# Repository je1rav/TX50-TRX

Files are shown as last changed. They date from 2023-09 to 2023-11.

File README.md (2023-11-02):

# TX50（CRkits共同購入プロジェクト）の改造

 CRkits共同購入プロジェクトで頒布されているTX50送信機（http://jl1kra.sakura.ne.jp/TX50R50.html
 ) を改造し，シンプルなAMトランシーバーにしました．  

## TX50送信機の複数周波数で通信可能なトランシーバーへの改造
TX50は元々JH1FCZ氏が開発された10mW出力のトランスレス50MHz帯コレクタ変調AM送信機をCRkits共同購入プロジェクトが復刻キット化したものです．  
キットでは水晶発振器で50.55MHzあるいは50.62MHzを発生させ，その周波数で運用します．  
QP-7Cの改造との場合と同様に，まず，発振段にSi5351モジュールを使用することで，複数周波数での使用を容易にしました．  
また，Si5351は，複数の端子に比較的自由な周波数の信号を出力できますので，それを利用したスーパーヘテロダイン受信機を作成し，トランシーバー化しました．  
受信機のAFアンプには，TX50送信機のマイクアンプ(LM386)を使い回し，スピーカー出力にしました．  
電源には006P(9V)を使用し，PTTスイッチで送受信を切り替えました． 

改造は以下の2点です．  

### 1．発振段のSi5351化
	Si5351モジュール（秋月電子）を使用し，発振出力をファイナル段に入力しました．  
	ファイナル段の入力は自己バイアス回路とし，Si5351の出力をコンデンサを介してベースに導入しています． 
	2N3904のベースーコレクタ間に自己バイアス用に100kΩの抵抗を接続しています． 
	T2とC13無しの直結状態で，無変調時に7.6mWの出力を確認しました．  
	新スプリアス規格のスプリアス領域の信号強度50μW(-13dBm)以下を満たしています． 
	Si5351モジュールは，Seeed Xiao RP2040でI2Cインターフェースを介して制御しました．  
	タクトスイッチで，プリセットした周波数を順次変更できるようにしました．  
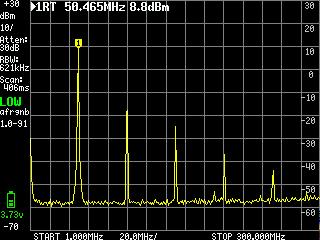
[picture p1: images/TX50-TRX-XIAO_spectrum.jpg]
スプリアス
  
TinySAによる送信スペクトル測定結果（T2とC13無し，無変調時）

### 2．シングルスーパー受信機を使用したトランシーバー化  
	QP-7Cの改造の場合と同様にラジオICであるCD2003を使用し，IF 450kHz(あるいは455kHz)で，セラミックフィルターによる帯域制限を行いました．  
	局所発振信号はSi5351モジュールから加えています．  
	AFアンプにはTX50のマイクアンプを，切り替えて使用しています．  
	プリRFアンプなしでの最終的な感度は50MHz帯で-75dbmのAM信号がかろうじて検知できる程度でした(TinySAと耳による)．  
	送受信の切り替えは，4回路2接点のプッシュスイッチを　PTTスイッチとして使用しました．  
   
回路図は，
回路図pdfファイル  
赤丸はTX50送信機キットの部品をそのまま使用，ピンク丸はキットで余った部品を流用，それ以外は別途準備した部品です．  
受信部はCD2003を使用したシングルスーパー受信機です．  
50MHz帯では感度が不足しそうですが，今回は送信機出力が10mWとQRPpなのでプリアンプなしで製作しました．  
IFフィルターにはLTMxxxYYが使用できます．とりあえず，LTM450IWで作りました．  
アンテナコネクタの近くのT2とC13はロッドアンテナを使用した場合のマッチング用ですので，使用しない時は取り付けないで，基板のT2の1番ピンと5番ピンをショートします．  
ロッドアンテナを使用する場合，この回路はGAWANTもどきで調整が必要です(具体的な調整は変更申請が終わってから行う予定です)．  
(option)で示された部品はOLED接続用，OLEDに対応した詳細な周波数変更用のタクトスイッチ，およびSSB受信用のBFO部品です．  
AGC電圧をSeeed Xiao RP2040のアナログ入力に接続してあるので，OLEDを繋げば信号強度の表示も可能なはずです．  
(option)部分の利用に関するプログラムは，現時点では作っておらず，具体的な作成計画もありません．  

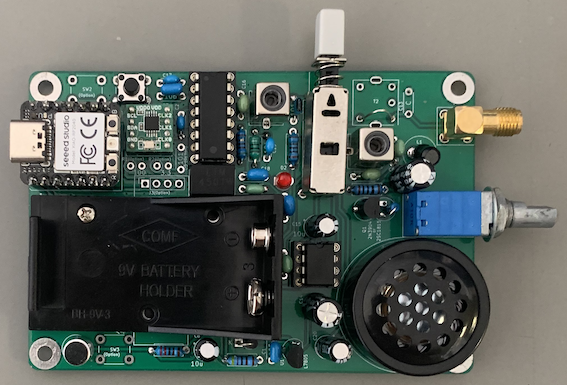
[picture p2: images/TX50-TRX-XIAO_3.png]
   
ロッドアンテナ不使用で部品をつけた状態（プロトタイプ基板）  
  
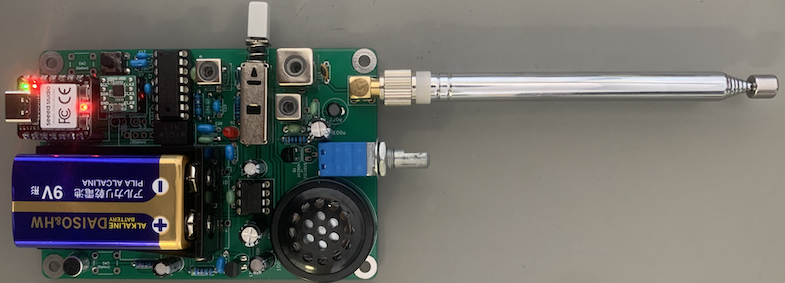
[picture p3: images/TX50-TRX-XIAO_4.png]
  
ロッドアンテナ仕様にした状態（プロトタイプ基板）  

受信機の入力段に送信機キットで余ったDIY7をBPFとして挿入していますので，受信感度が最大になるようにコアを調整する必要があります．  
もちろん送信部のコアの調整も必要です

#### Seeed Xiao RP2040用スケッチは"TX50-TRX-XIAO.ino"です．  
	ボードマネージャは，Earlephilhower版 Raspberry Pi Pico/RP2040が使用できます．
	この際，ボードとしてSeeed Xiao RP2040を選んでください． 
 	また，消費電流を減らすため．CPU Speedは最低の50MHzにセットして下さい． 
  	プログラムの62行目の”set_sys_clock_khz(18000, true);”を有効にすると，システムクロックは18MHzまで下がって，消費電流がさらに減少します． 
   	但し，このクロック周波数ではUSBシリアル通信機能が失われますので，新たに別のプログラムを書き込みたい場合は．一旦，プログラミングモードにする必要があります． 
   	（プログラミングモードは，BOOTボタンを押しながらRESETボタンを押すと入れます． USBメモリの様にマウントされます．） 
	今回はUSB Audioを使用していないので，Raspberry Pi Pico mbed版は必要ありません． 
	どうしてもmbed版を使いたい場合はQP-7C_RP2040のページを参照して下さい． 
	SI5351aの制御には，"Etherkit SI5351"ライブラリーを使用しました． 
	選択周波数はオンボードのカラーLEDの色で表示することにし，その制御には"Adafruit_NeoPixel"ライブラリーを使用しました． 
	#define FREQ_0 から　#define FREQ_6 で運用したい周波数を設定します． 
	タクトスイッチを押すたびに，次々に周波数が変化し，カラーLEDの色が変わります． 
	
#### JLCPCB用のガーバーファイルは"TX50-TRX-XIAO_gerber.zip"で，Kicadのファイルは"TX50-TRX-XIAO_kicad.zip"です．  
	実際にはプロトタイプ版で動作テストをしており， これはそのマイナーチェンジ版(現時点では未テスト)です．  
 
#### ケースの3Dプリンタデータファイルは"TX50-TRX-XIAO-BOX_stl.zip"です．  
	M3 35mmネジ 4本で固定できます．  
 	USB充電式9V充電池(006P型)用の充電穴をつけたパネルも含めました．  
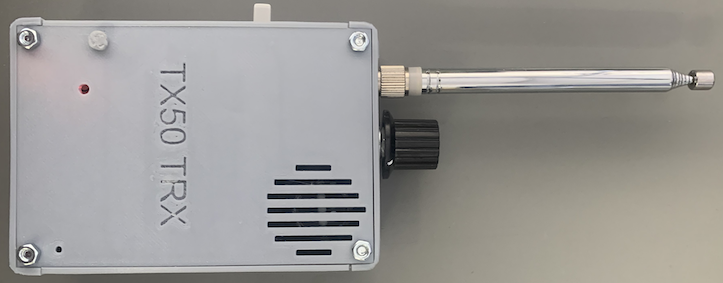
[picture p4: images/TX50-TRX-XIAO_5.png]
  

#### 必要部品(2023年9月27日時点の価格)  
	TX50キット：CRkits共同購入プロジェクト，1850円 + 180円（送料）　http://jl1kra.sakura.ne.jp/TX50R50.html  
	Seeed Xiao RP2040：たとえば秋月電子 830円　https://akizukidenshi.com/catalog/g/gM-17044/
	秋月電子Si5351モジュール：秋月電子，500円　https://akizukidenshi.com/catalog/g/gK-10679/  
	8ピンICソケット（秋月電子Si5351モジュール用）：1個
	CD2003GP：たとえばaitendo，165円　https://www.aitendo.com/product/1528
	16ピンICソケット（CD2003GP用）：1個
	LTM455IW or LTM450IW：秋月電子，1個110円(LTM455IW) or 10個300円(LTM450IW) https://akizukidenshi.com/catalog/g/gP-16374/ or https://akizukidenshi.com/catalog/g/gP-16052/
	三端子レギュレーター　５Ｖ１００ｍＡ：例えば，TA78L05S　秋月電子，20円　https://akizukidenshi.com/catalog/g/gI-08973/
	分割ロングピンソケット　１×４２（Seeed Xiao RP2040ソケット受けが必要ならば）：秋月電子，1個80円　https://akizukidenshi.com/catalog/g/gC-05779/  
	ピンヘッダ　１×４０：（Seeed Xiao RP2040用）秋月電子，1個35円　https://akizukidenshi.com/catalog/g/gC-00167/  
	プッシュボタンPS-42F42：aliexpress（ロックなし，あるいはロック付き）やaitendo（ロック付き 44円，ただし準備中）
	基板取付用２連ボリューム　スイッチ付　A10ｋΩ：秋月電子，180円　https://akizukidenshi.com/catalog/g/gP-12579/
	基板取付用スピーカーユニットUGSM30A-8-01：秋月電子，120円　https://akizukidenshi.com/catalog/g/gP-09270/
	006P電池ホルダー BH-9V-3P24：秋月電子，50円　https://akizukidenshi.com/catalog/g/gP-08160/
	タクトスイッチ：例えば秋月電子，15円　https://akizukidenshi.com/catalog/g/gP-17166/
	整流用ショットキーダイオード：例えば１Ｓ４，秋月電子10本　140円　https://akizukidenshi.com/catalog/g/gI-16384/
	電解コンデンサ100μF(オーディオ出力用）C21：1個  
	積層セラミックコンデンサー106（CD2003のAGC用）C8： 1個
	積層セラミックコンデンサー105（電源，オーディオ用）C1, C11，C19： 3個    
	積層セラミックコンデンサー104（CD2003用）C18，C20： 2個
	積層セラミックコンデンサー103（CD2003のLO入力用）C3： 1個
	(積層)セラミックコンデンサー101（TX50入力用，RF受信用）C2，C12： 2個
	インダクター10uH（CD2003用）： 1個（マイクロインダクター，アキシャル型）
	抵抗　51Ω(CD2003のLO入力用）：1個  
	
	ロッドアンテナを使用する場合は，FCZコイル１０ｍｍ角50MHz用（サトー電気）とコンデンサー（15pF?）
	ロッドアンテナ：例えば，秋月電子，WH-281SM　500円　https://akizukidenshi.com/catalog/g/gP-00236/

# TX27-TRX

CRkits共同購入プロジェクトで頒布されているTX50送信機（http://jl1kra.sakura.ne.jp/TX50R50.html
 ) を改造し，シンプルな玩具トランシーバーにしました．  

## 27MHz帯玩具トランシーバーへの改造  
玩具トランシーバーは，電波が著しく微弱な無線局で，免許不要ですが，そのための条件があります．  
「電波法施行規則第六条第一項第二号」  
「電波が著しく微弱な無線局についての総務省の告示(第472号（郵政省告示第708号）」  
です．  
総務省に確認したところ，このラジオマイク用の条件下でトランシーバーとして使用して良いそうです．  
27MHz帯A3E(AM)では，周波数範囲27.12MHz±162.72kHzで通信が可能です．  
但し，無線設備から500mの距離において、その電界強度が200μV/m以下である必要があります．  
これに関連して，電波研究所季報Vol.6 No.22 35-38 (1960)に論文があります．  
https://www.nict.go.jp/publication/kiho/06/022/Kiho_Vol06_No022_pp035-038.pdf  
この論文によると，P<sub>0</sub>=0.27W程度の終段管(3S4)で，1.03mのロッドアンテナを使用した場合，27MHz帯で上記条件を満たしています．  
この論文での実際の出力は不明ですが，10mWよりは大きいと考えられますので，今回の場合，1m程度のロッドアンテナで十分に規制値を下回るものと考えられます．  

改造は，上記のTX50送信機のトランシーバー化に加えて，以下の3点です．  
### 1．FCZトランスの変更  
	２つの7mm角のFCZコイルとコンデンサーを，それぞれ25MHz用FCZコイルと33pFコンデンサに交換します．
### 2．アンテナとマッチング回路  
	玩具トランシーバーは，電波が著しく微弱な無線局で，免許不要ですが，そのための条件があります．  
	上記の電波研究所の論文を参考にすると，今回の場合，1m程度のロッドアンテナで十分に規制値を下回るものと考えられます．
	そこで，GAWANTもどきのマッチング回路をつけてロッドアンテナを付けました(上記の回路図通り，10mm角FCZコイル28MHz用+33pFコンデンサ)．
	ケースのトップパネルの3Dプリンタデータファイルは"TX27-TRX-XIAO_BOX_top.stl"です．
### 3．スケッチ
	27MHz帯はCB無線として長らく使われてきており，今回の玩具トランシーバーの可能周波数範囲もそれを含んでいます．  
	そこで，CB周波数8ch(26.968MHz, 26.976MHz, 27.04MHz, 27.08MHz, 27.088MHz, 27.112MHz, 27.12MHz, 27.144MHz)をプリセットしました．  
	タクトスイッチで，プリセットした周波数を順次変更できるようにし，選択周波数はXiao RP2040のオンボードのカラーLEDの色で表示しています．  
	カラーLEDの色は，それぞれ（赤，緑，...，白，消灯）です．
	Arduino IDE用スケッチは，"TX27-TRX-XIAO.ino"です．
	
### 調整
	受信感度および送信出力が最大になるようにT2，T1およびT3のコアの位置を調整して下さい．

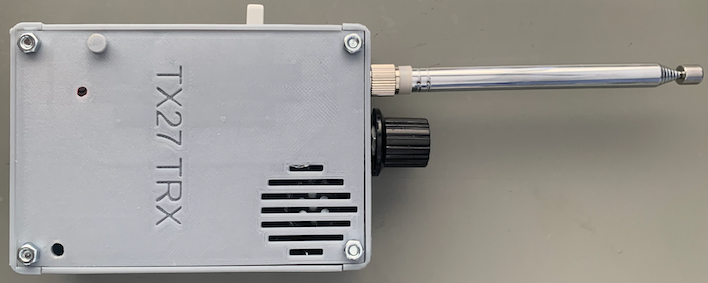
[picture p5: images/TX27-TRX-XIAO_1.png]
  
箱に入れた状態

#### 必要部品(TX50トランシーバーとの差分)  
	FCZコイル7ｍｍ角25MHz用（サトー電気）とコンデンサー（33pF）X 2組
	FCZコイル１０ｍｍ角28MHz用（サトー電気）とコンデンサー（33pF）

## TX50トランシーバーの28MHz帯AMトランシーバーへの改造  
アマチュア無線の28MHz帯は，周波数が近いので，コアの調整は必要ですが，ハードウエアはそのまま使用できます．  
ロッドアンテナ以外のアンテナを使用する場合，10mm角FCZコイル28MHz用+33pFコンデンサ)を取り付けないで，T2の1番ピンと5番ピンをショートし，お好きなアンテナをお付けください．  
Arduino IDE用スケッチ"TX27-TRX-XIAO.ino"の#define FREQ_0〜#define FREQ_7に運用周波数を設定して下さい．  
ケースのトップパネルの3Dプリンタデータファイルは"TX28-TRX-XIAO_BOX_top.stl"です．

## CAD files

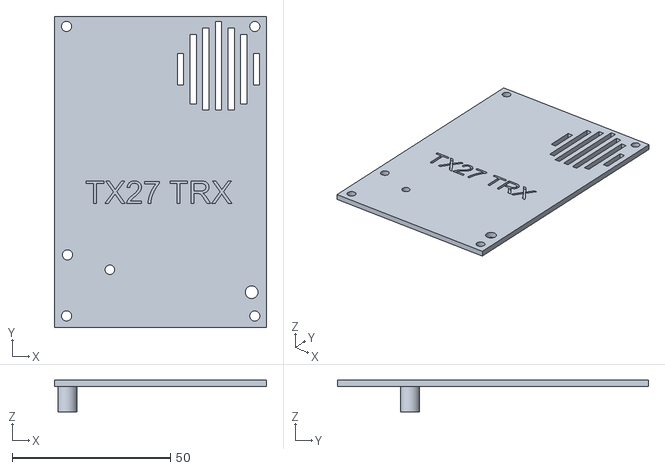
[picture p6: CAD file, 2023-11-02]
TX27-TRX-XIAO_BOX_top.stl
67.0 x 98.4 x 10.0

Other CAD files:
TX28-TRX-XIAO_BOX_top.stl

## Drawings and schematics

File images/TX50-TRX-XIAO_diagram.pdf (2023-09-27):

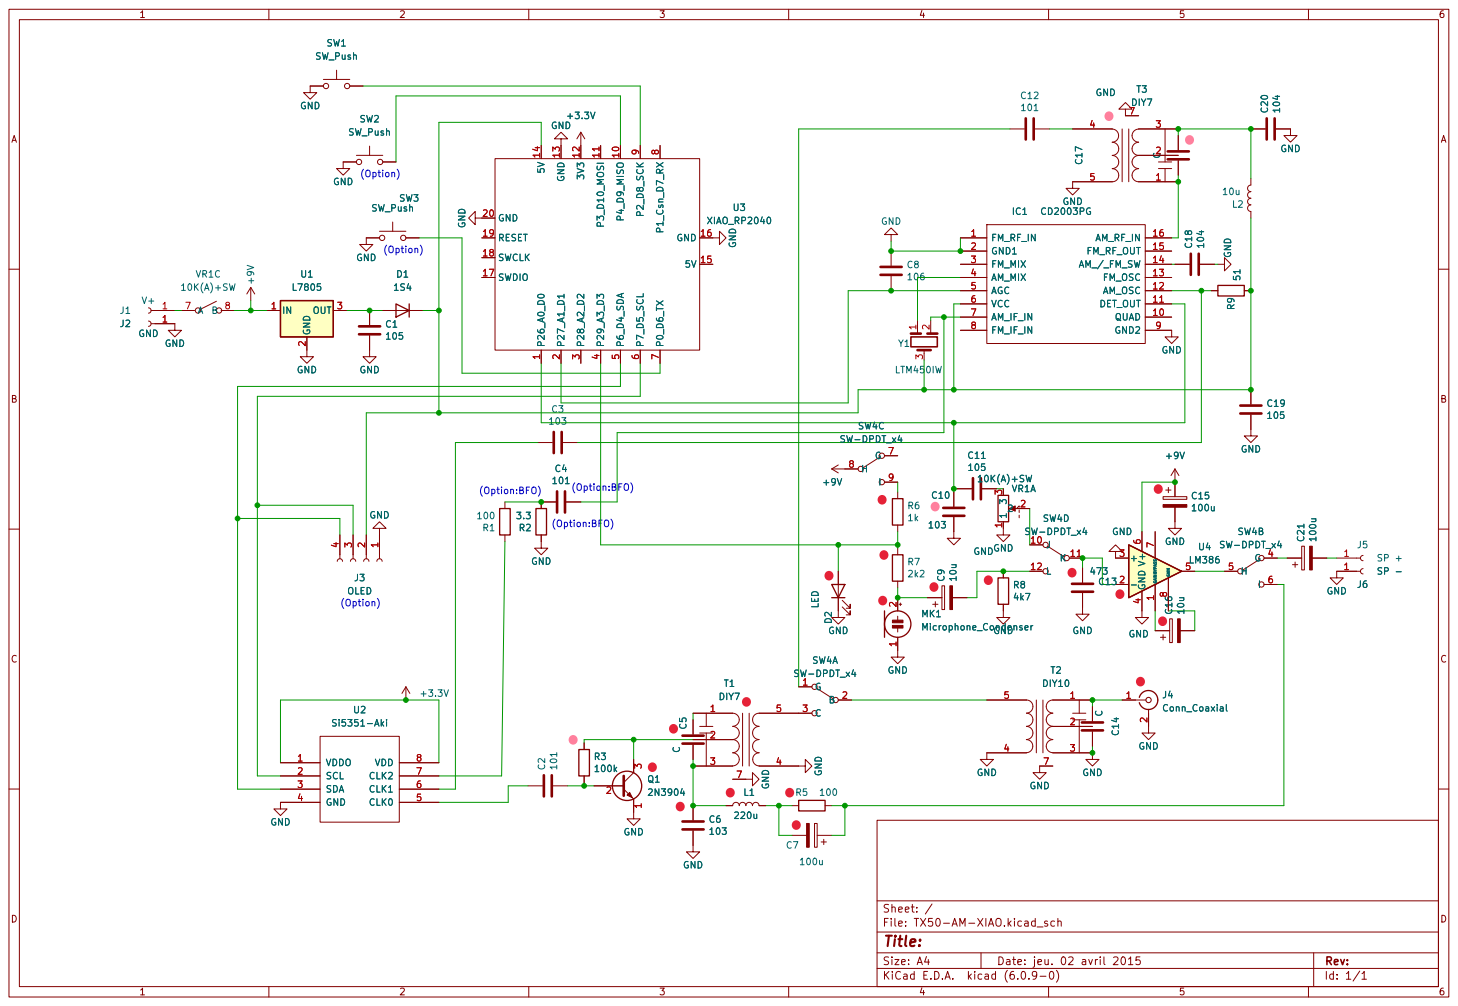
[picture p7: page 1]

2 OUT 3 GND GND GND

(Option:BFO)

1 U2 Si5351-Aki VDDO 1 SCL 2 SDA 3 GND 4 CLK0 5 CLK1 6 CLK2 7 VDD 8 GND

File: TX50-AM-XIAO.kicad_sch Sheet: /

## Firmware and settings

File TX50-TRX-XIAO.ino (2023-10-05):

/*
 * Copyright (C) 2023- Hitoshi Kawaji <je1rav@gmail.com>
 * 
 * TX50_XIAO_RP2040.ino
 * 
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
 * You should have received a copy of the GNU General Public License
 * along with this program.  If not, see <https://www.gnu.org/licenses/>.
 */

#define Si5351_CAL -22000 // Calibrate for your Si5351 module.
#define FREQ_IF 450000 // IF frequency in Hz: Calibrate for your IF filter.  

#define N_FREQ 7 // number of using RF frequencies　(<= 7)
#define FREQ_0 50400000 // RF frequency in Hz
#define FREQ_1 50500000 // in Hz
#define FREQ_2 50550000 // in Hz
#define FREQ_3 50600000 // in Hz
#define FREQ_4 50620000 // in Hz
#define FREQ_5 50650000 // in Hz
#define FREQ_6 50700000 // in Hz
uint64_t Freq_table[N_FREQ]={FREQ_0,FREQ_1,FREQ_2,FREQ_3,FREQ_4,FREQ_5,FREQ_6}; // Freq_table[N_FREQ]={FREQ_0,FREQ_1, ...}

#define pin_SW1 2 //pin for freq change switch (input)
#define pin_TX_STATUS 29 //pin to detect transmittion (input)
#define pin_RED 17 //pin for onboard Red LED (output)
#define pin_GREEN 16 //pin for onboard GREEN LED (output)
#define pin_BLUE 25 //pin for onboard BLUE LED (output) 
#define pin_LED_POWER 11 //pin for onboard NEOPIXEL LED power (output)
#define pin_LED 12 //pin for onboard NEOPIXEL LED (output)

#include <Wire.h>
#include <si5351.h>  //"Etherkit Si5351"
Si5351 si5351;

#include <Adafruit_NeoPixel.h>
Adafruit_NeoPixel pixels(1, pin_LED);
#define BRIGHTNESS 5  //max 255
uint32_t colors[] = {pixels.Color(BRIGHTNESS, 0, 0), pixels.Color(0, BRIGHTNESS, 0), pixels.Color(0, 0, BRIGHTNESS), pixels.Color(BRIGHTNESS, BRIGHTNESS, 0), pixels.Color(BRIGHTNESS, 0, BRIGHTNESS), pixels.Color(0, BRIGHTNESS, BRIGHTNESS), pixels.Color(BRIGHTNESS, BRIGHTNESS, BRIGHTNESS)};

uint64_t RF_freq;   // RF frequency (Hz)
int64_t IF_freq;   // IF frequency (Hz)
int local_osc = 1;  //1 -> local oscilation frequency is lower than that of receiving frequency , -1 -> local oscilation frequency is higher than that of receiving frequency
int C_freq = 0;  //FREQ_x: In this case, FREQ_0 is selected as the initial frequency. 
int Tx_Status =0;

#include "pico/stdlib.h"  //for use set_sys_clock_khz(): change the system clock frequency

void setup() {
  
  //After using the following features, you will need to enter programming mode when uploading a new program.
  //Programming mode can be entered by holding down the BOOTSEL button when RP2040 is turned on.
  //set_sys_clock_khz(18000, true);   //CPU clock is down to 18000kHz (18MHz) to reduce the power consumption.

  //Digital pin setting ----- 
  pinMode(pin_SW1, INPUT_PULLUP); //SW (freq. change)
  pinMode(pin_TX_STATUS, INPUT); //SW (freq. change)

  pinMode(pin_RED, OUTPUT); //On →　LOW (for RED LED)
  pinMode(pin_GREEN, OUTPUT); //On →　LOW (for GREEN LED)
  pinMode(pin_BLUE, OUTPUT); //On →　LOW (for BLUE LED)
  pinMode(pin_LED_POWER, OUTPUT); //NEOPIXEL LED

  //I2c initialization-----  
  Wire.begin();

  //si5351 initialization-----  
  int32_t cal_factor = Si5351_CAL;
  RF_freq = Freq_table[C_freq];
  si5351.init(SI5351_CRYSTAL_LOAD_8PF, 0, 0); 
  si5351.set_correction(cal_factor, SI5351_PLL_INPUT_XO);
  si5351.set_pll(SI5351_PLL_FIXED, SI5351_PLLA);
  si5351.set_freq(RF_freq*100ULL, SI5351_CLK0);  //for TX
  si5351.drive_strength(SI5351_CLK0, SI5351_DRIVE_8MA);
  si5351.output_enable(SI5351_CLK0, 0);
  IF_freq = FREQ_IF * local_osc;
  si5351.set_freq((RF_freq-IF_freq)*100ULL, SI5351_CLK1);  //for RX
  si5351.drive_strength(SI5351_CLK1, SI5351_DRIVE_2MA);
  si5351.output_enable(SI5351_CLK1, 0);
  
  //NEOPIXEL LED initialization-----
  digitalWrite(pin_LED_POWER, HIGH);  //NEOPIXEL LED ON
  pixels.begin();  // initialize the NEOPIXEL
  pixels.setPixelColor(0, colors[C_freq]);
  pixels.show();

  //transceiver initialization-----
  si5351.output_enable(SI5351_CLK0, 0);   //TX osc. off
  si5351.output_enable(SI5351_CLK1, 1);   //RX osc. on

  //Onboard LED initialization-----
  digitalWrite(pin_RED, HIGH);
  digitalWrite(pin_GREEN, LOW); //Green LED ON
  digitalWrite(pin_BLUE, HIGH);
}

void loop() {
  if (digitalRead(pin_TX_STATUS) == 1 ) transmit();
  else {
    receive();
    freqChange();
  }
}

void transmit(){
  if (Tx_Status==0){
    si5351.output_enable(SI5351_CLK1, 0);   //RX osc. off
    si5351.output_enable(SI5351_CLK0, 1);   //TX osc. on
    Tx_Status=1;
    digitalWrite(pin_RED, 0);
    digitalWrite(pin_GREEN, 1);
    //digitalWrite(pin_BLUE, 1);
  }
}

void receive(){
  if (Tx_Status==1){
    si5351.output_enable(SI5351_CLK0, 0);   //TX osc. off
    si5351.output_enable(SI5351_CLK1, 1);   //RX osc. on
    Tx_Status=0;
    digitalWrite(pin_RED, 1);
    digitalWrite(pin_GREEN, 0);
    //digitalWrite(pin_BLUE, 1);
  }
}

void freqChange(){
  if (digitalRead(pin_SW1)==LOW){
    delay(100);
    if  (digitalRead(pin_SW1)==LOW){
      C_freq++;
      if  (C_freq >= N_FREQ){
        C_freq = 0;
      }
    }
    RF_freq = Freq_table[C_freq];
    si5351.set_freq(RF_freq*100ULL, SI5351_CLK0);
    si5351.set_freq((RF_freq-IF_freq)*100ULL, SI5351_CLK1);
    pixels.setPixelColor(0, colors[C_freq]);
    pixels.show();
    delay(100);
  }
}

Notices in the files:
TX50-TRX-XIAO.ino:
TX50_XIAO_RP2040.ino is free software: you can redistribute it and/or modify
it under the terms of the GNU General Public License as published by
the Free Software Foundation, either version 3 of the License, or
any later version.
